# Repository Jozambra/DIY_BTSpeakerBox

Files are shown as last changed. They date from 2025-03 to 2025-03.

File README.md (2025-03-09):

# DIY_BTSpeakerBox
This project presents a DIY design for a speaker box that can recieve audio data from an analog 3.5mm Jack or a BT module. It incorporates a 3-band Equalizer custom PCB that also functions as the main power distribution board.

The main components of the board are present in the HW wiring diagram attached; it consits of a main PCB that incorporates a PreAmp with 3 band EQ, a BT audio reciever module, and a 30W stereo class D amplifier. A 3D encasing is also provided (Step and FreeCAD project files are included in the Enclosure branch). A generic BT and Class D amp modules are used in this project; however, the main PCB is compatible with any alternative solution (either custom or commercial) that uses a similar voltage. Nontheless, note that the main PS (which is, effectively, directly connected to the amp) must be of at least 12V to ensure the proper operation of the 9V regulator.

This amplifier set up has been tested with a 12V 3A power supply over a low-medium volume range; over a 2 hour listening session no excessive heating was detected in either module of the product.

NOTE: A Mains to 12-24V power supply is not included in this design, it recieved power from a standard barrel adaptor using an external supply. It is highly recommeded to use a good quality supply to reduce noise in the PreAmp (This alternative has provided decent results during testing: https://a.co/d/3dhSiTF).

NOTE2: Rev 1.1 is the modified version of the main PCB with some mods from the Rev 1.0 already installed. this design is not tested; however, only minor changes were made so its functionallity is highly likely

Bellow is a list of the current known issues of the project:

-Main PCB is missing mounting wholes for easy attachment to the box (included in the newest revision but missing on the 3D desingn file).
-Noise floor of the PreAmp is noticeable at low volumes (TO DO: reduce all resistances by a factor of 10 and consider using non-carbon based resistors to reduce thermal noise)
-Missing Soft Start circuit to prevent Popping on Speakers during Power-Up/Down.
-Certain combinations of the bass/tremble/mid potentiometers generate an audible oscillation that is transmitted to the spakers; needs further investigation in the filter Op-Amp loop.

Feel free to adapt this project to your particular needs, all the design files are provided as Open Source. Furthermore, if a solution to any of the listed issues is found, a pull request with the approach would be highly appreciated.

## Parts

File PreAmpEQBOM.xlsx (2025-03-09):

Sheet: PreAmpEQR1.0
Reference | Value | Qty | Datasheet | Footprint | DNP | added
C1,C2 | 1n | 2 | ~ | Capacitor_SMD:C_0805_2012Metric_Pad1.18x1.45mm_HandSolder
C3,C8 | 330n | 2 | ~ | Capacitor_SMD:C_0805_2012Metric_Pad1.18x1.45mm_HandSolder
C4,C6 | 200n | 2 | ~ | Capacitor_SMD:C_0805_2012Metric_Pad1.18x1.45mm_HandSolder
C5,C12,C14,C19,C20,C21,C22 | 10u | 7 | ~ | Capacitor_SMD:C_0805_2012Metric_Pad1.18x1.45mm_HandSolder
C7 | 1u | 1 | ~ | Capacitor_SMD:C_0805_2012Metric_Pad1.18x1.45mm_HandSolder
C9,C10,C17,C18,C31 | 100n | 5 | ~ | Capacitor_SMD:C_0805_2012Metric_Pad1.18x1.45mm_HandSolder
C11,C13 | 33p | 2 | ~ | Capacitor_SMD:C_0805_2012Metric_Pad1.18x1.45mm_HandSolder
C15,C16 | 2.2u | 2 | ~ | Capacitor_SMD:C_0805_2012Metric_Pad1.18x1.45mm_HandSolder
C23,C29 | 22n | 2 | ~ | Capacitor_SMD:C_0805_2012Metric_Pad1.18x1.45mm_HandSolder
C24,C28 | 4.7n | 2 | ~ | Capacitor_SMD:C_0805_2012Metric_Pad1.18x1.45mm_HandSolder
C25,C27 | 47n | 2 | ~ | Capacitor_SMD:C_0805_2012Metric_Pad1.18x1.45mm_HandSolder
C26,C30 | 10n | 2 | ~ | Capacitor_SMD:C_0805_2012Metric_Pad1.18x1.45mm_HandSolder
CR1 | VSSAF510-M3/H | 1 | VSSAF510-M3/H | CR_SLIMSMA_DO-221AC_VIS
F1 | MF-GSMF300/36X-2 | 1 | MF-GSMF300/36X-2 | MFGSM:FUSE_MF-GSMF_BRN
J1 | DCJ200-10-A-XX-K_REVA | 1 |  | DCJ200:GCT_DCJ200-10-A-XX-K_REVA
J2,J5 | 1935174 | 2 |  | TERM BLK 3POS:PHOENIX_1935174
J3,J4,J6 | 691137710002 | 3 |  | TERM BLK 2POS:691137710002
L1 | ACM7060-701-2PL-TL01 | 1 | ACM7060-701-2PL-TL01 | ACM7060:IND_ACM7060_TDK
R1 | 0R | 1 | ~ | Resistor_SMD:R_0805_2012Metric_Pad1.20x1.40mm_HandSolder
R2,R5,R7 | DNI | 3 | ~ | Resistor_SMD:R_0805_2012Metric_Pad1.20x1.40mm_HandSolder
R3,R4,R13,R14,R15,R24,R25,R26 | 10k | 8 | ~ | Resistor_SMD:R_0805_2012Metric_Pad1.20x1.40mm_HandSolder
R6,R8,R32,R35 | 50k | 4 | ~ | Resistor_SMD:R_0805_2012Metric_Pad1.20x1.40mm_HandSolder
R9,R10,R11,R12 | PTN16-A100230K1B2 | 4 |  | PTN16:POT_PTN16-A100230K1B2
R16,R17,R18,R19 | 44k | 4 | ~ | Resistor_SMD:R_0805_2012Metric_Pad1.20x1.40mm_HandSolder
R20,R21,R27,R28 | 3.3k | 4 | ~ | Resistor_SMD:R_0805_2012Metric_Pad1.20x1.40mm_HandSolder
R22,R23,R29,R30 | 3.6k | 4 | ~ | Resistor_SMD:R_0805_2012Metric_Pad1.20x1.40mm_HandSolder
R31,R33 | 25k | 2 | ~ | Resistor_SMD:R_0805_2012Metric_Pad1.20x1.40mm_HandSolder
R34,R36 | 20k | 2 | ~ | Resistor_SMD:R_0805_2012Metric_Pad1.20x1.40mm_HandSolder
RV1 | AVRH16A2C270KT200NA8 | 1 | ~ | Resistor_SMD:R_0603_1608Metric_Pad0.98x0.95mm_HandSolder
U1 | NCV7805BDTRKG | 1 | NCV7805BDTRKG | DPAK-3_ONS
U2 | NCV7809BD2TR4G | 1 | NCV7809BD2TR4G | D2PAK3_ONS
U3,U4,U5 | LM833MX/NOPB | 3 | LM833MX/NOPB | LM833MX:M08A_TEX

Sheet: PreAmpEQ_R1.1
Reference | Value | Datasheet | Footprint | Qty | DNP
C1,C2 | 1n | ~ | Capacitor_SMD:C_0805_2012Metric_Pad1.18x1.45mm_HandSolder | 2
C3,C8 | 330n | ~ | Capacitor_SMD:C_0805_2012Metric_Pad1.18x1.45mm_HandSolder | 2
C4,C6 | 200n | ~ | Capacitor_SMD:C_0805_2012Metric_Pad1.18x1.45mm_HandSolder | 2
C5,C12,C14,C19,C20,C21,C22 | 10u | ~ | Capacitor_SMD:C_0805_2012Metric_Pad1.18x1.45mm_HandSolder | 7
C7 | 1u | ~ | Capacitor_SMD:C_0805_2012Metric_Pad1.18x1.45mm_HandSolder | 1
C9,C10,C17,C18,C31 | 100n | ~ | Capacitor_SMD:C_0805_2012Metric_Pad1.18x1.45mm_HandSolder | 5
C11,C13 | 33p | ~ | Capacitor_SMD:C_0805_2012Metric_Pad1.18x1.45mm_HandSolder | 2
C15,C16 | 2.2u | ~ | Capacitor_SMD:C_0805_2012Metric_Pad1.18x1.45mm_HandSolder | 2
C23,C29 | 22n | ~ | Capacitor_SMD:C_0805_2012Metric_Pad1.18x1.45mm_HandSolder | 2
C24,C28 | 4.7n | ~ | Capacitor_SMD:C_0805_2012Metric_Pad1.18x1.45mm_HandSolder | 2
C25,C27 | 47n | ~ | Capacitor_SMD:C_0805_2012Metric_Pad1.18x1.45mm_HandSolder | 2
C26,C30 | 10n | ~ | Capacitor_SMD:C_0805_2012Metric_Pad1.18x1.45mm_HandSolder | 2
C32,C33 | 22u | ~ | Capacitor_SMD:C_0805_2012Metric_Pad1.18x1.45mm_HandSolder | 2
CR1 | VSSAF510-M3/H | VSSAF510-M3/H | CR_SLIMSMA_DO-221AC_VIS | 1
F1 | MF-GSMF300/36X-2 | MF-GSMF300/36X-2 | MFGSM:FUSE_MF-GSMF_BRN | 1
J1 | DCJ200-10-A-XX-K_REVA |  | DCJ200:GCT_DCJ200-10-A-XX-K_REVA | 1
J2,J5 | 1935174 |  | TERM BLK 3POS:PHOENIX_1935174 | 2
J3,J4,J6 | 691137710002 |  | TERM BLK 2POS:691137710002 | 3
L1 | ACM7060-701-2PL-TL01 | ACM7060-701-2PL-TL01 | ACM7060:IND_ACM7060_TDK | 1
R1 | 0R | ~ | Resistor_SMD:R_0805_2012Metric_Pad1.20x1.40mm_HandSolder | 1
R2 | DNI | ~ | Resistor_SMD:R_0805_2012Metric_Pad1.20x1.40mm_HandSolder | 1
R3,R4,R13,R14,R15,R24,R25,R26 | 10k | ~ | Resistor_SMD:R_0805_2012Metric_Pad1.20x1.40mm_HandSolder | 8
R5,R7 | 11k3 | ~ | Resistor_SMD:R_0805_2012Metric_Pad1.20x1.40mm_HandSolder | 2
R6,R8,R32,R35 | 50k | ~ | Resistor_SMD:R_0805_2012Metric_Pad1.20x1.40mm_HandSolder | 4
R9,R10,R11,R12 | PTN16-A100230K1B2 |  | PTN16:POT_PTN16-A100230K1B2 | 4
R16,R17,R18,R19,R37,R38,R39,R40 | 22k | ~ | Resistor_SMD:R_0805_2012Metric_Pad1.20x1.40mm_HandSolder | 8
R20,R21,R27,R28 | 3.3k | ~ | Resistor_SMD:R_0805_2012Metric_Pad1.20x1.40mm_HandSolder | 4
R22,R23,R29,R30 | 3.6k | ~ | Resistor_SMD:R_0805_2012Metric_Pad1.20x1.40mm_HandSolder | 4
R31,R33 | 25k | ~ | Resistor_SMD:R_0805_2012Metric_Pad1.20x1.40mm_HandSolder | 2
R34,R36 | 20k | ~ | Resistor_SMD:R_0805_2012Metric_Pad1.20x1.40mm_HandSolder | 2
R41,R42 | 1k | ~ | Resistor_SMD:R_0805_2012Metric_Pad1.20x1.40mm_HandSolder | 2
RV1 | AVRH16A2C270KT200NA8 | ~ | Resistor_SMD:R_0603_1608Metric_Pad0.98x0.95mm_HandSolder | 1
U1 | NCV7805BDTRKG | NCV7805BDTRKG | DPAK-3_ONS | 1
U2 | NCV7809BD2TR4G | NCV7809BD2TR4G | D2PAK3_ONS | 1
U3,U4,U5 | LM833MX/NOPB | LM833MX/NOPB | LM833MX:M08A_TEX | 3
BT module | VHM-314 | VHM-314 | https://www.aliexpress.com/item/1005006614243125.html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 | 1
3.5 mm Plug | ACJS-MV35-3 | ACJS-MV35-3 |  | 1
DPDT switch | SW-T3-4B-A-A3-S2 | SW-T3-4B-A-A3-S2 |  | 1
SpeakerOutConnertor | Push-In Jack |  | https://www.aliexpress.com/item/1005008159607589.html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 | 1
Power amp | TPA3110 | TPA3110 | https://www.aliexpress.com/item/1005006124814134.html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 | 1
Notes: | All caps in the power lines must be rated at least at 50V
 | All caps should use X7R or X5R materials
 | All sinal caps should be at least 25 V
 | The lower resistor tolerance the better
 | All chip components are 0805s

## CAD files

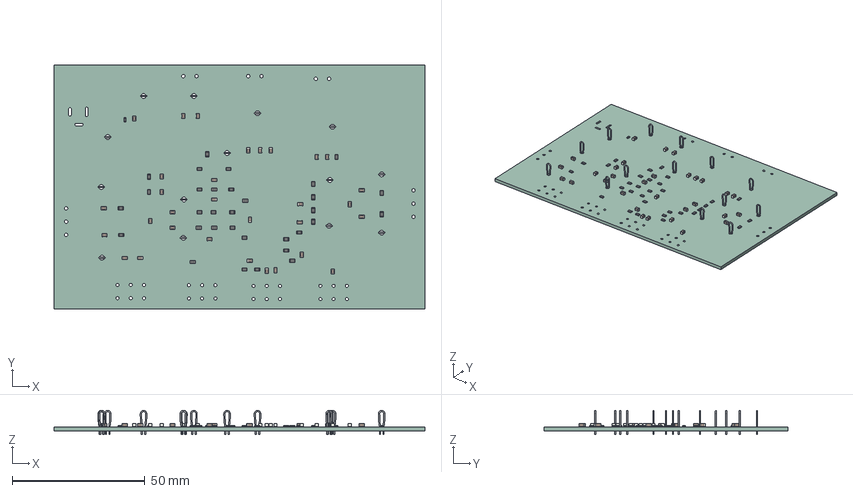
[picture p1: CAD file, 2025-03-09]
PreAmpEQ/PreAmpEQ.step
140.0 x 92.2 x 9.15 mm
R_0805_2012Metric x 32
TestPoint_Loop_D2.50mm_Drill1.85mm x 14
C_0805_2012Metric x 31
R_0603_1608Metric
PreAmpEQ_PCB

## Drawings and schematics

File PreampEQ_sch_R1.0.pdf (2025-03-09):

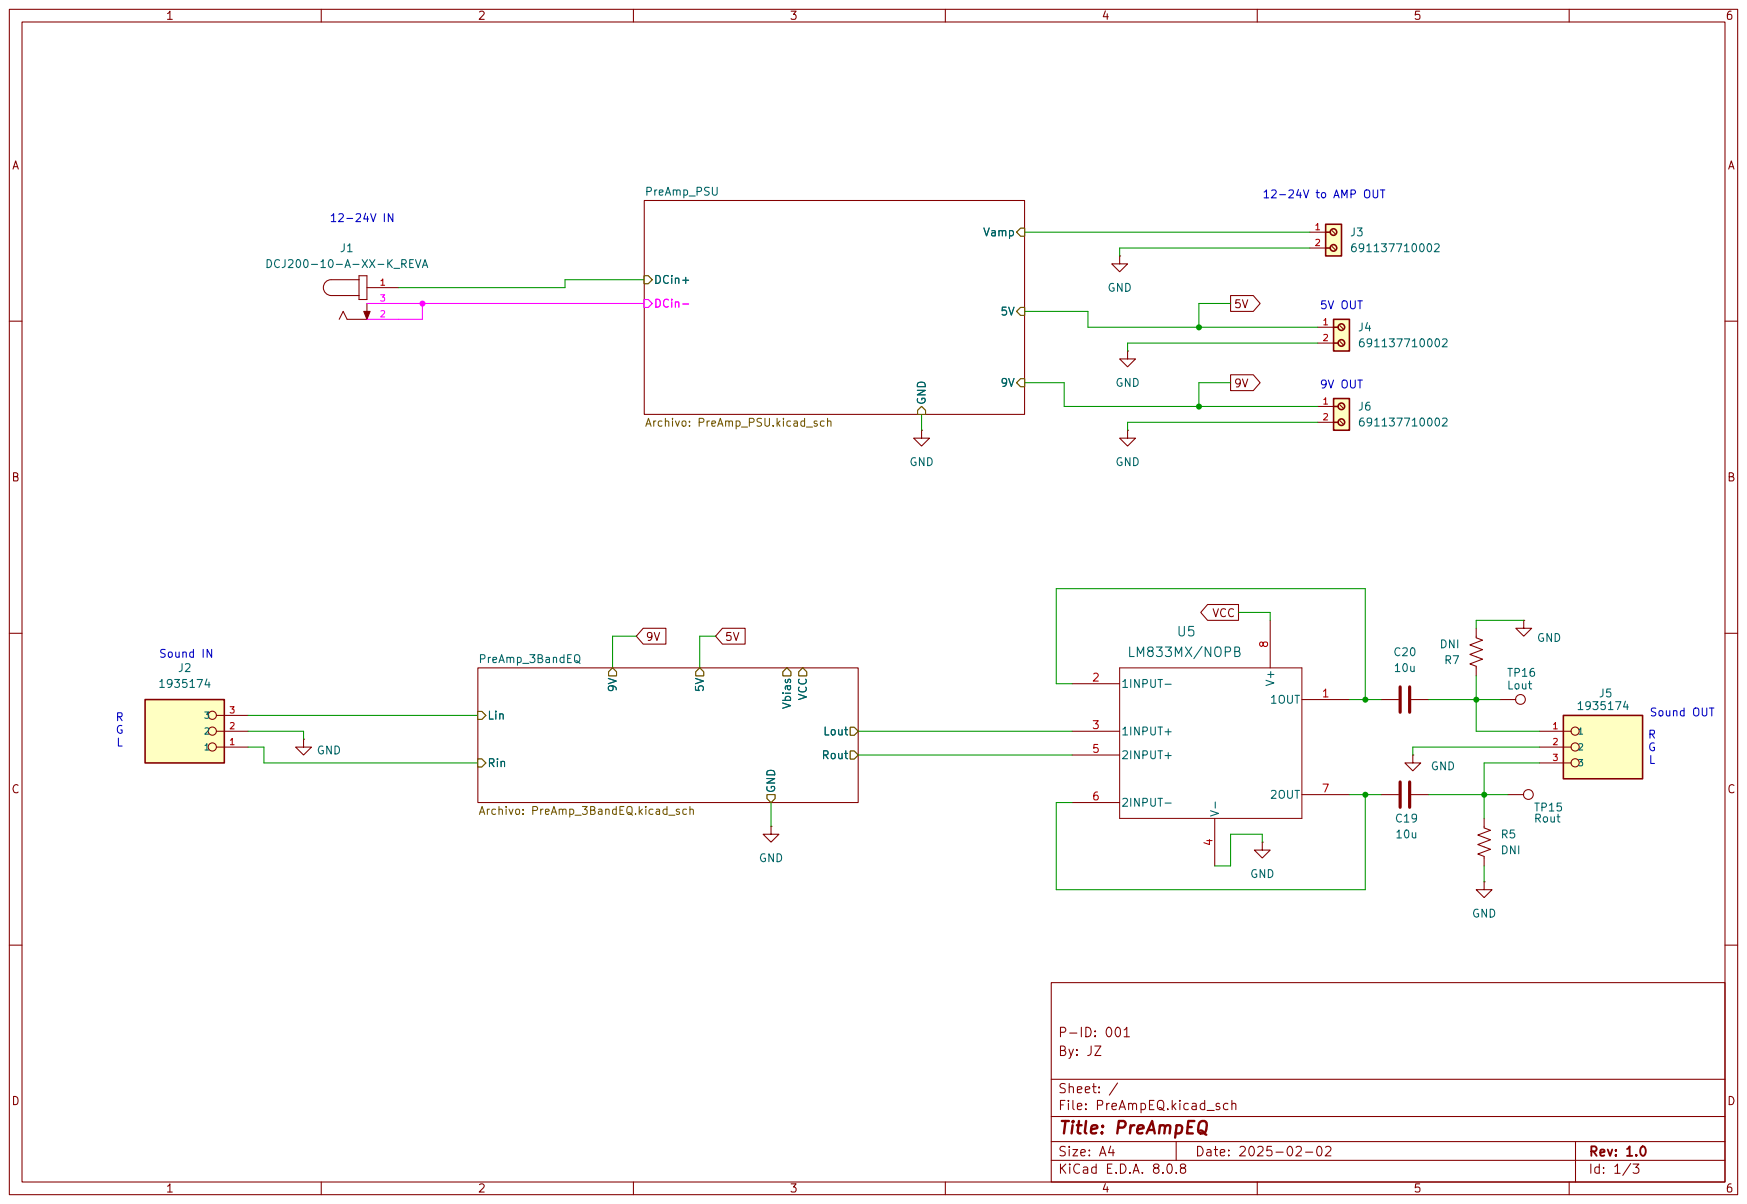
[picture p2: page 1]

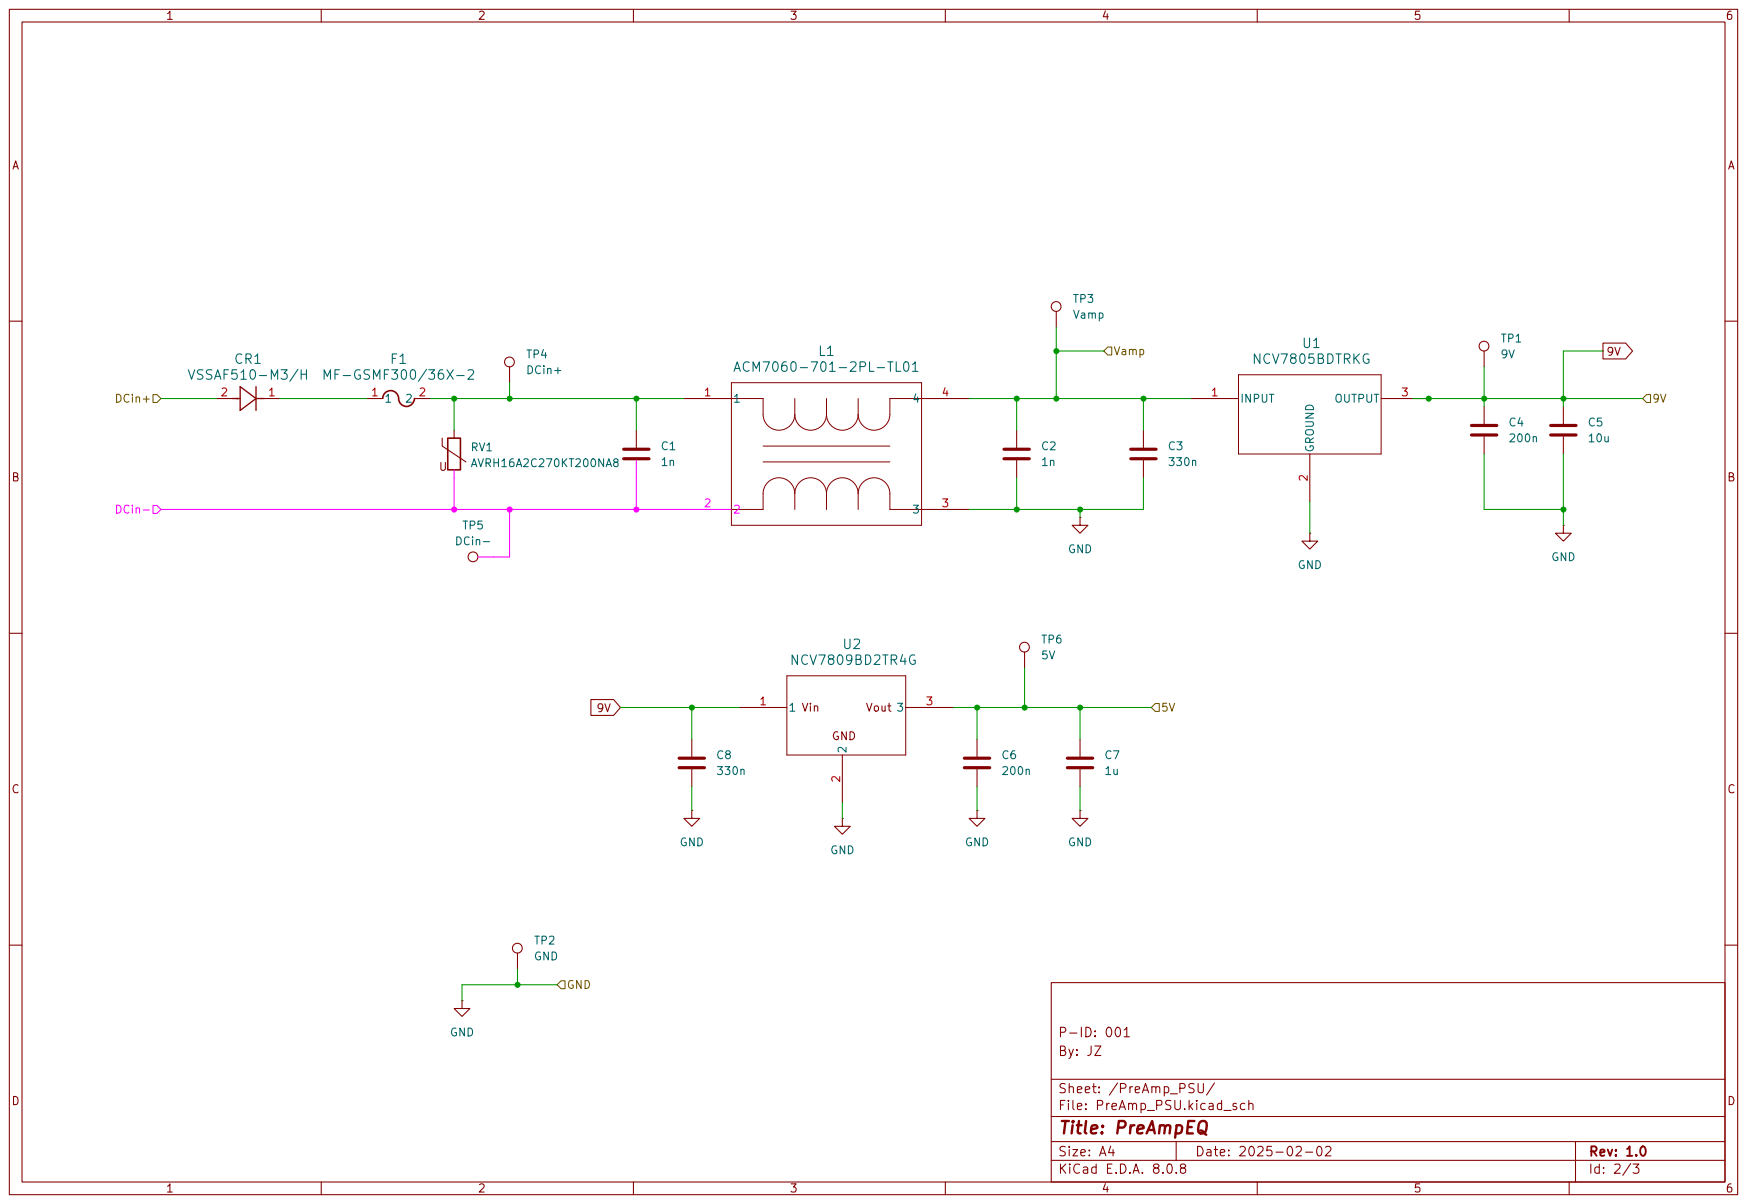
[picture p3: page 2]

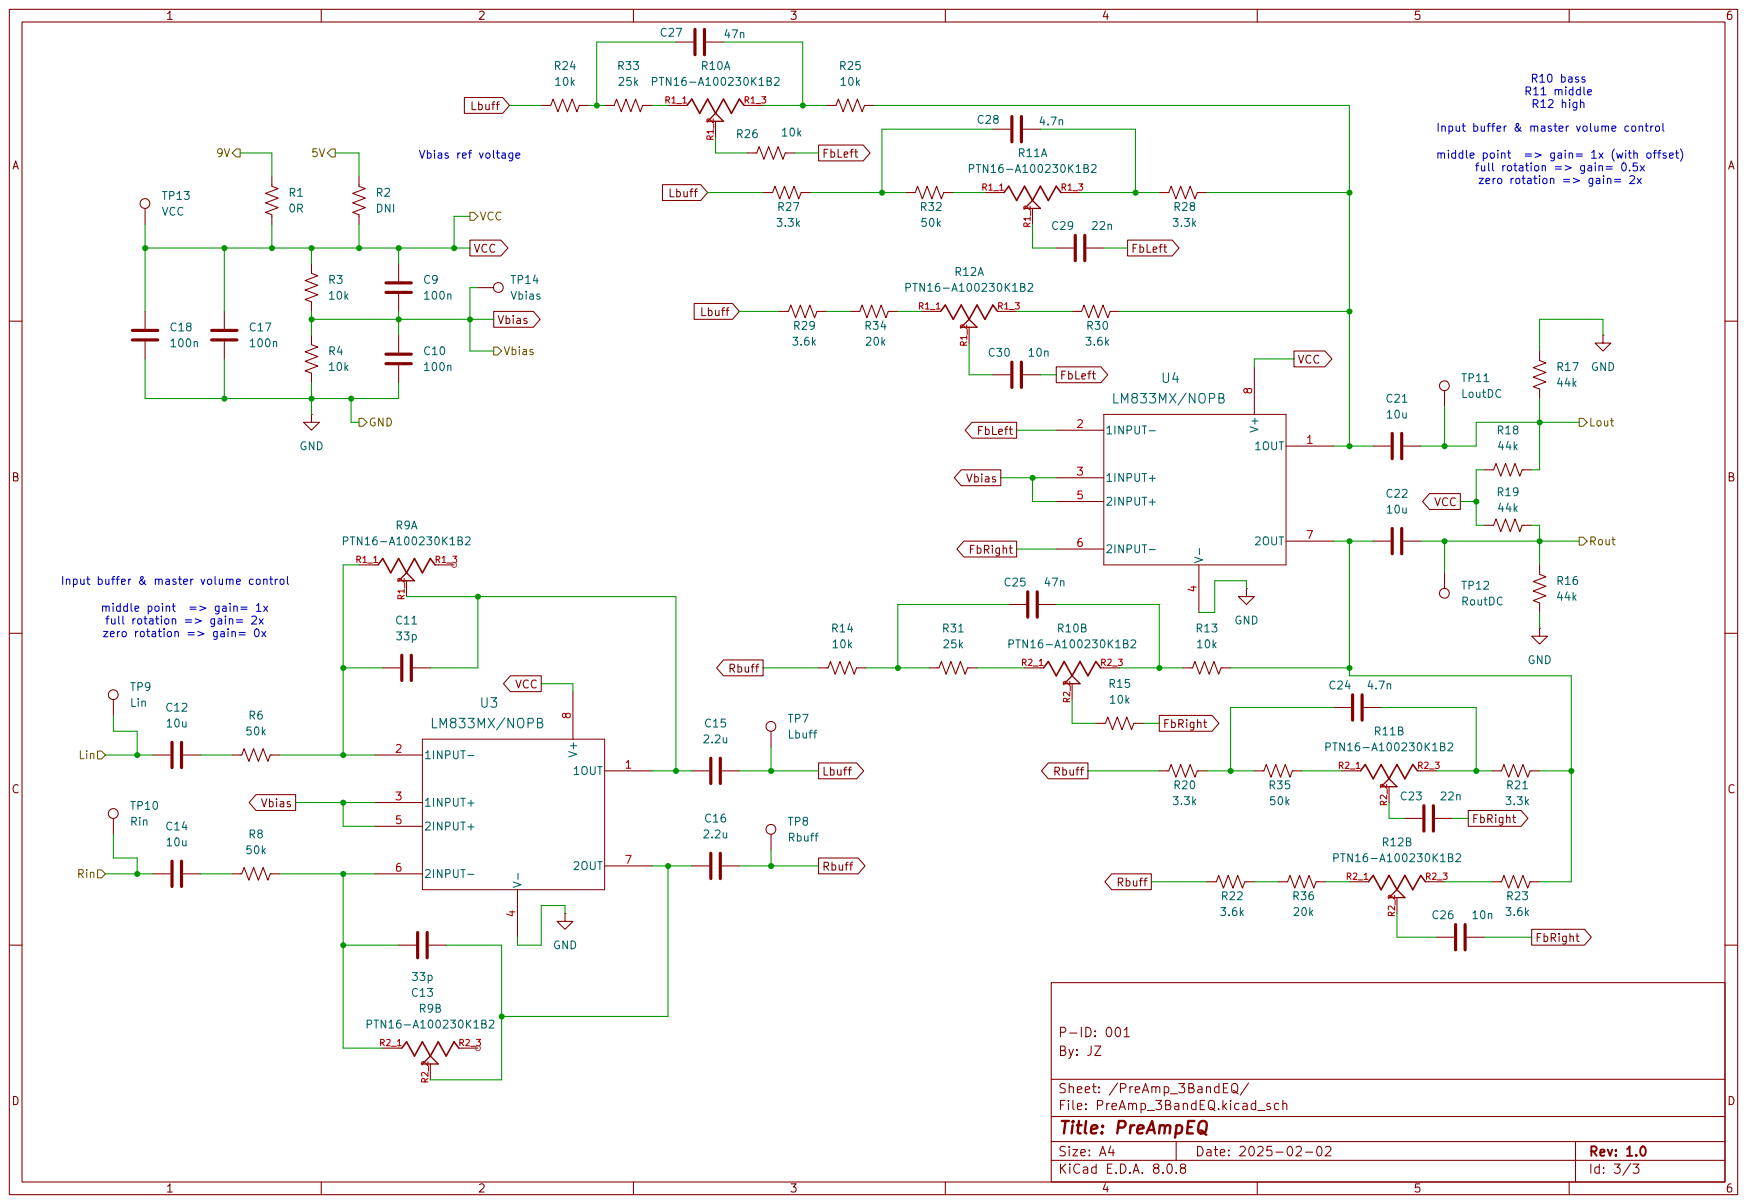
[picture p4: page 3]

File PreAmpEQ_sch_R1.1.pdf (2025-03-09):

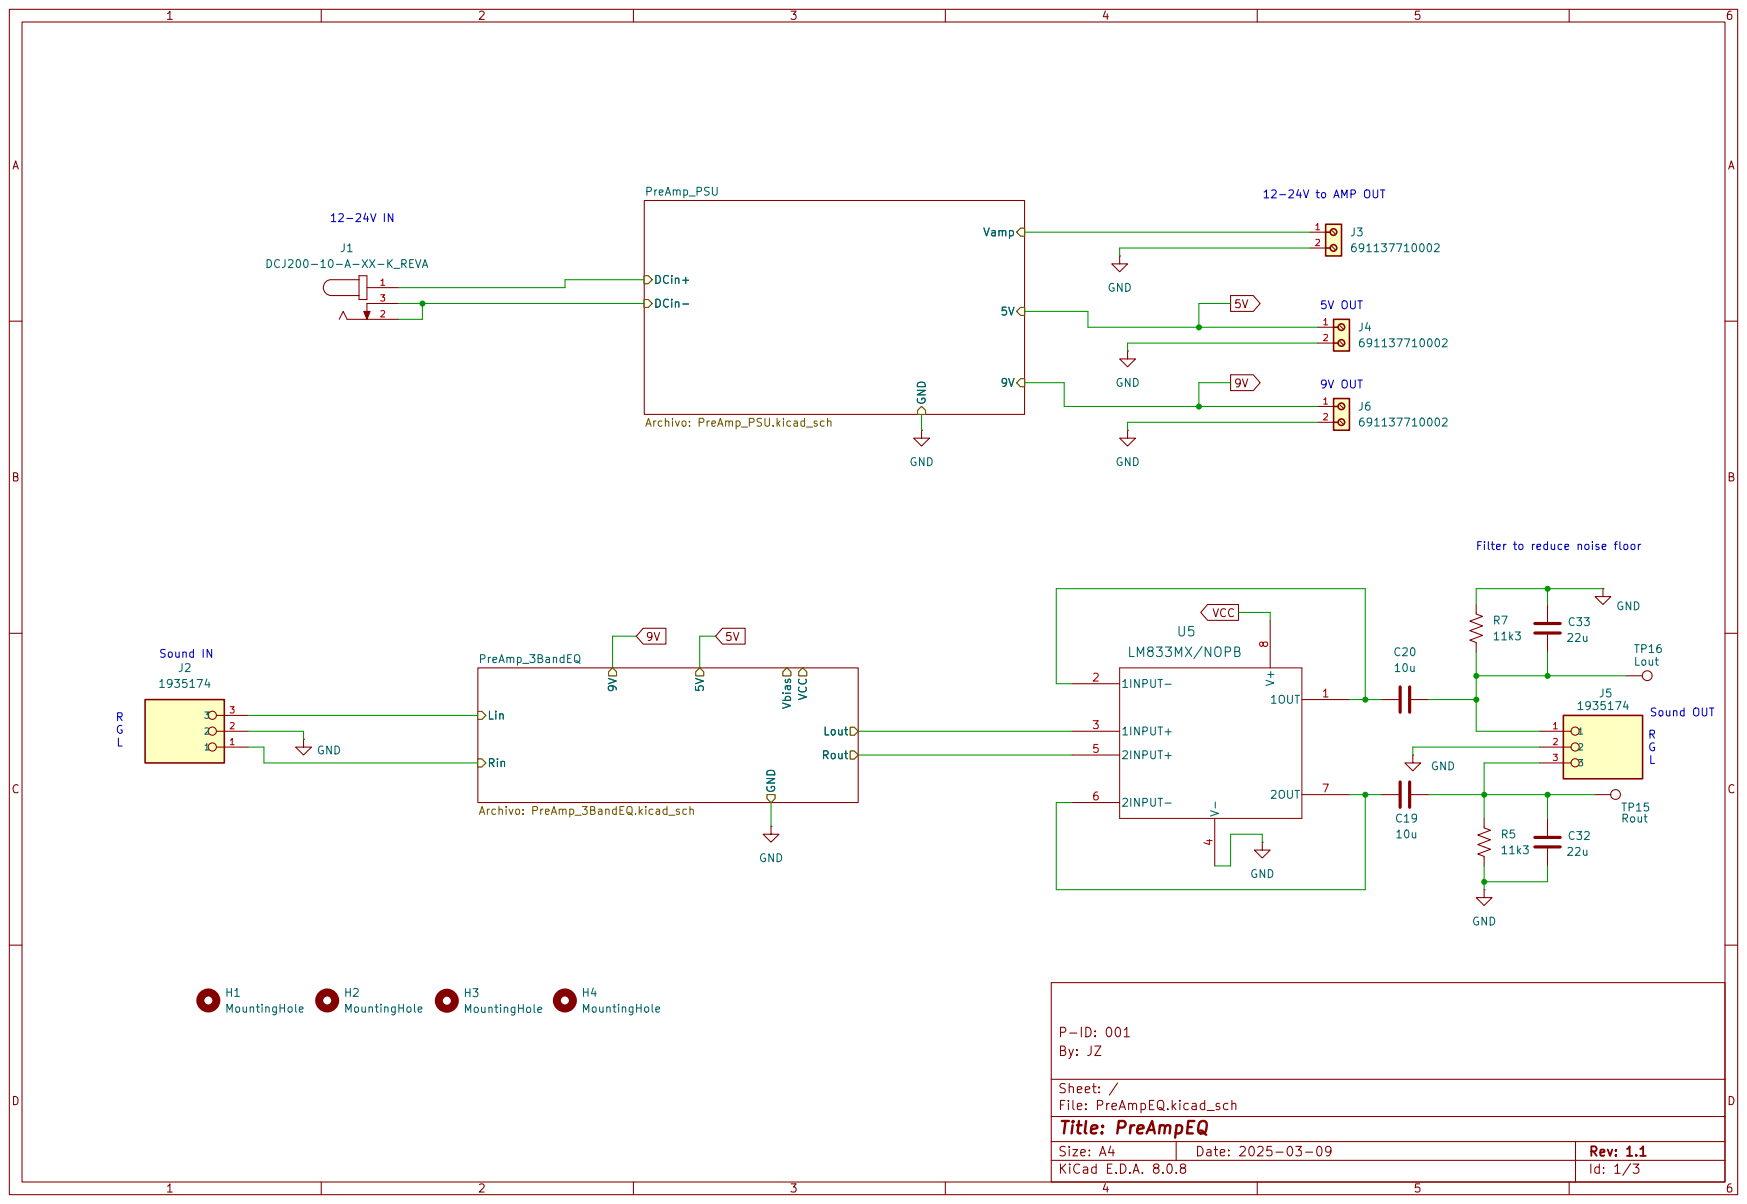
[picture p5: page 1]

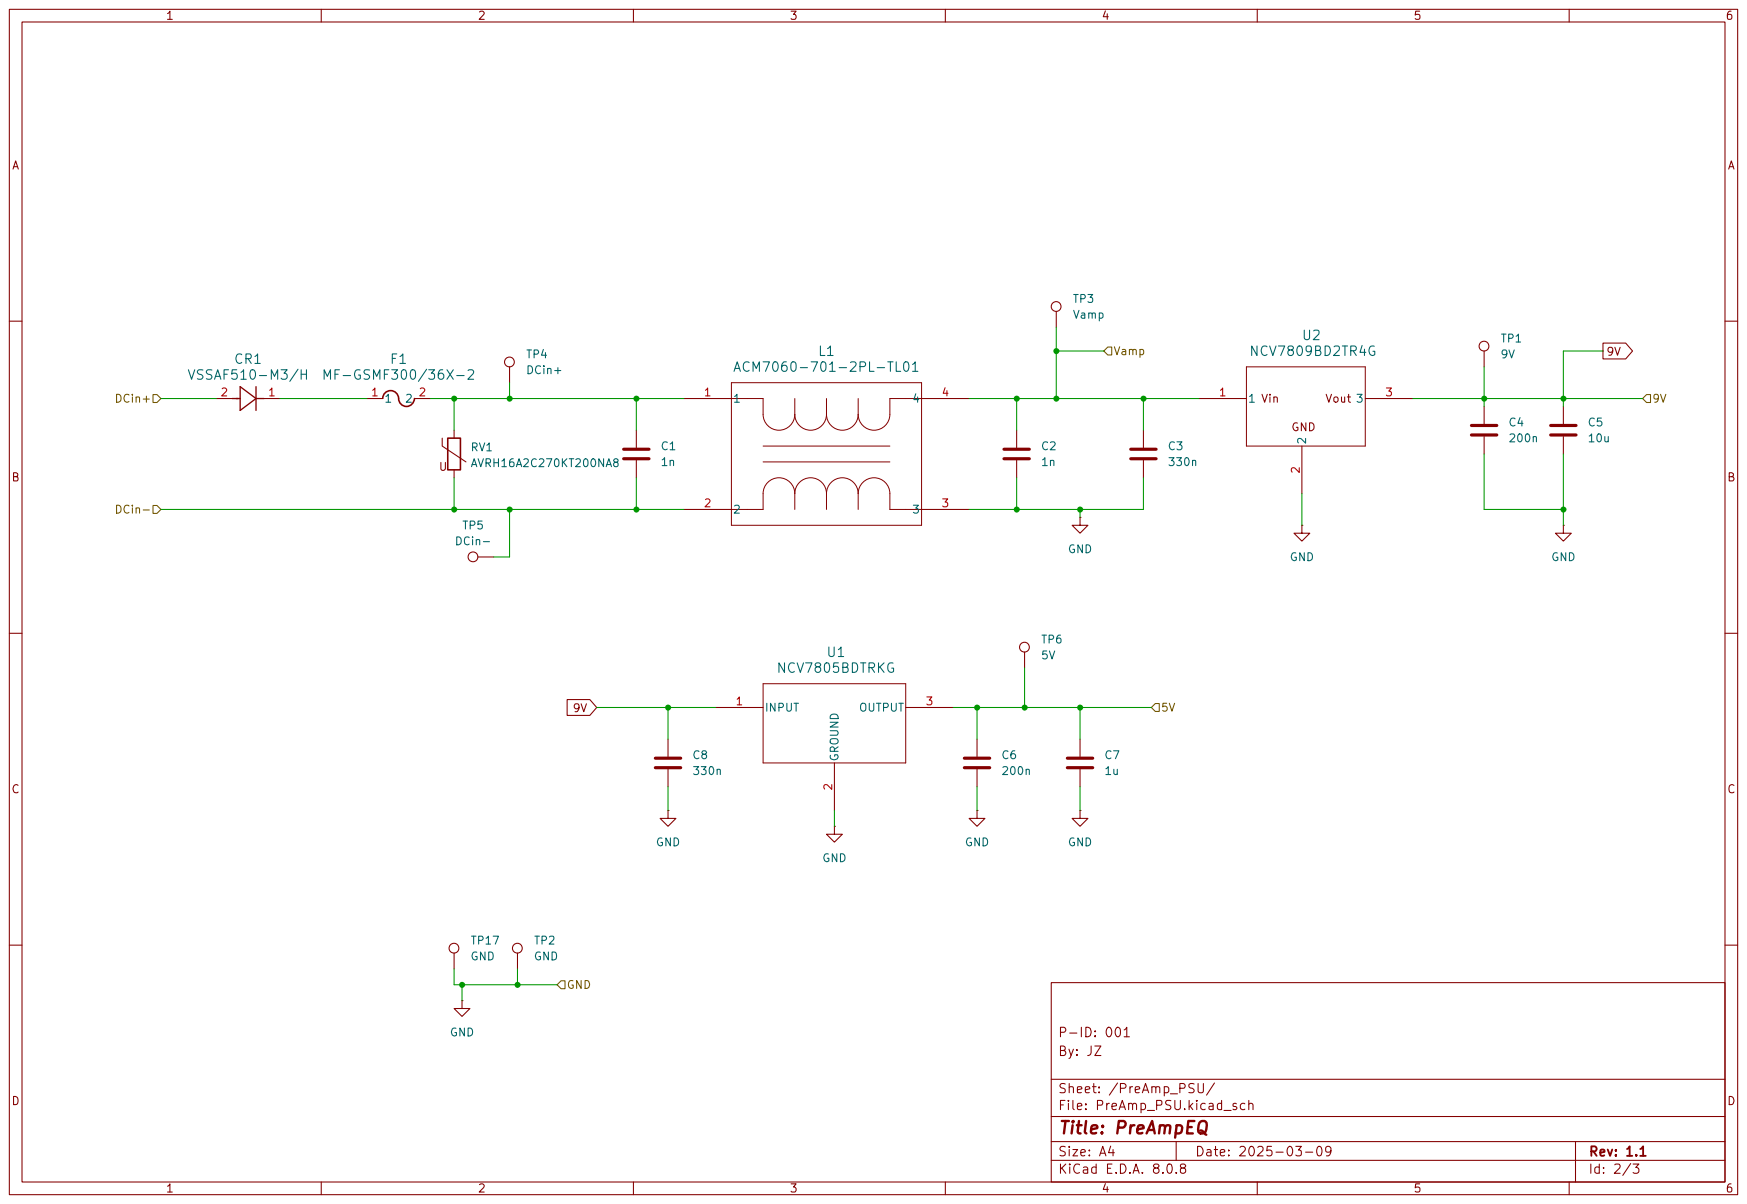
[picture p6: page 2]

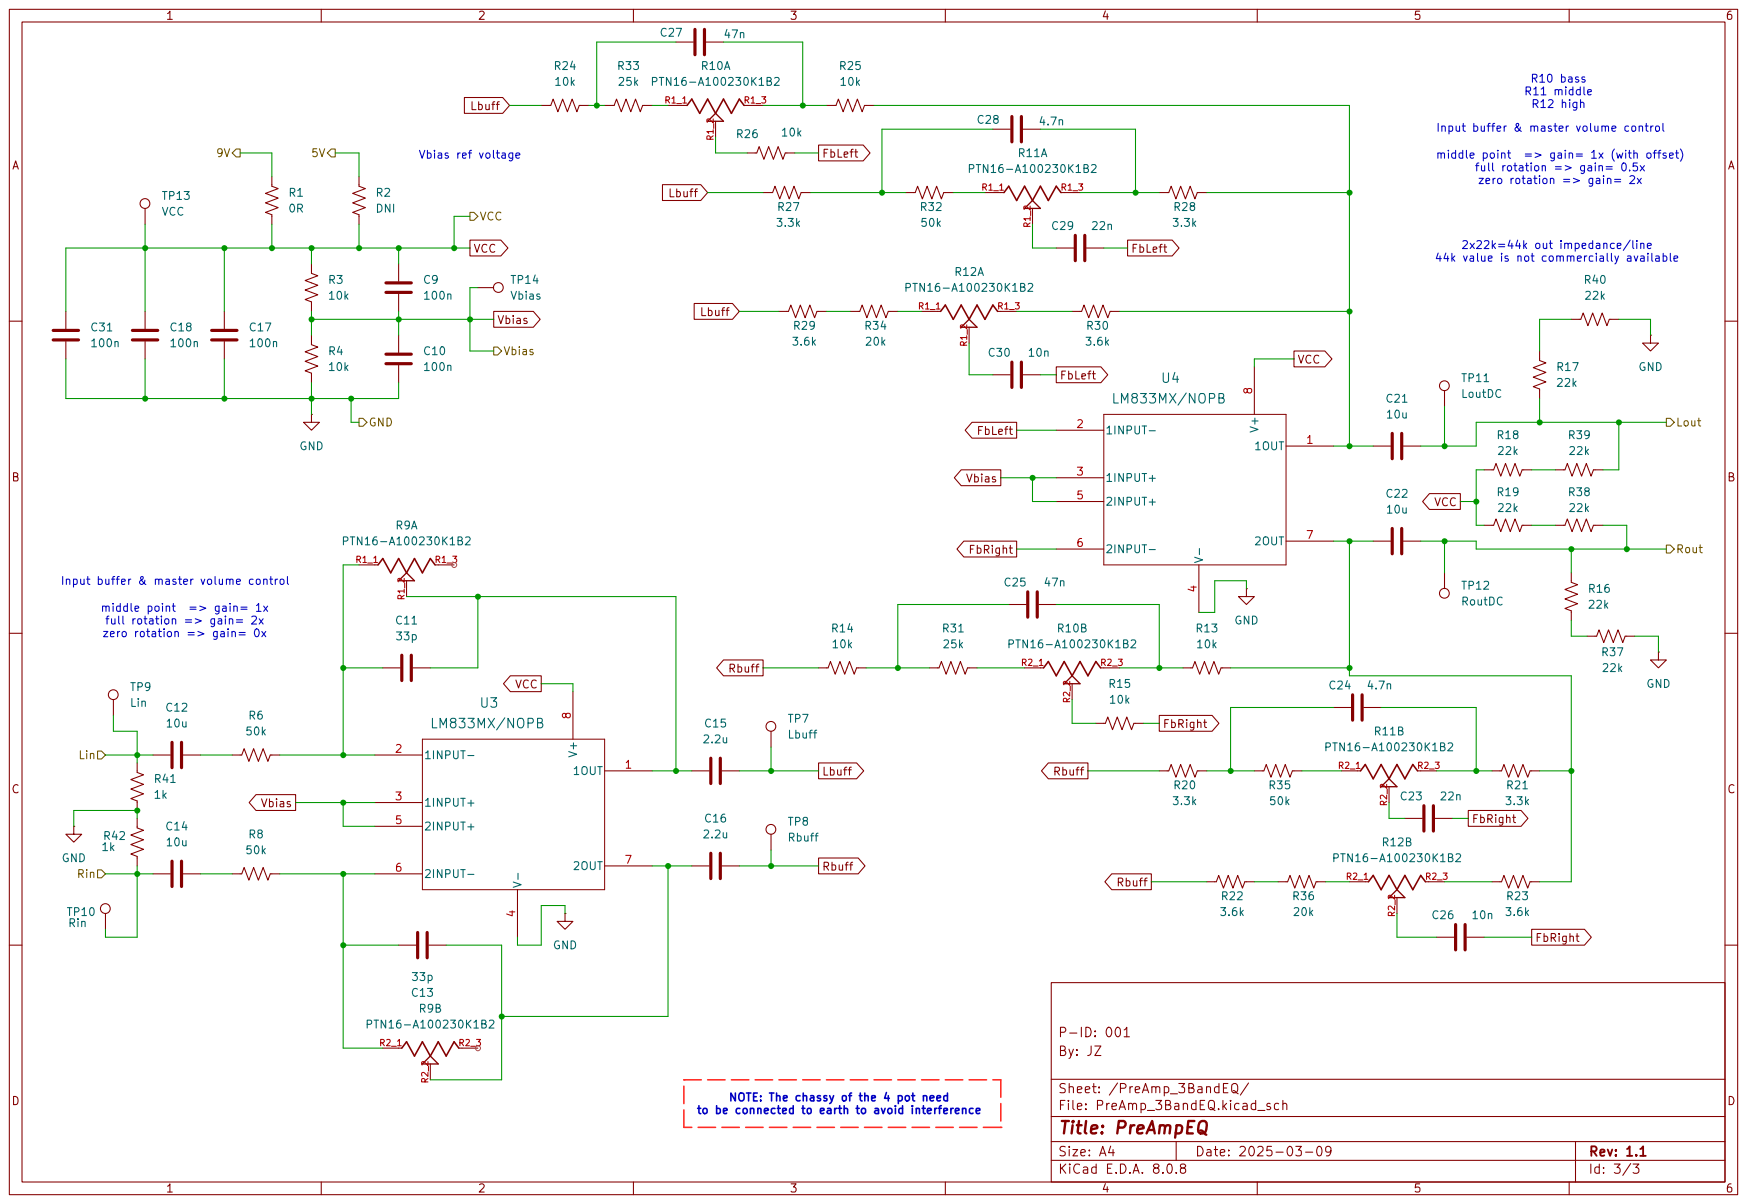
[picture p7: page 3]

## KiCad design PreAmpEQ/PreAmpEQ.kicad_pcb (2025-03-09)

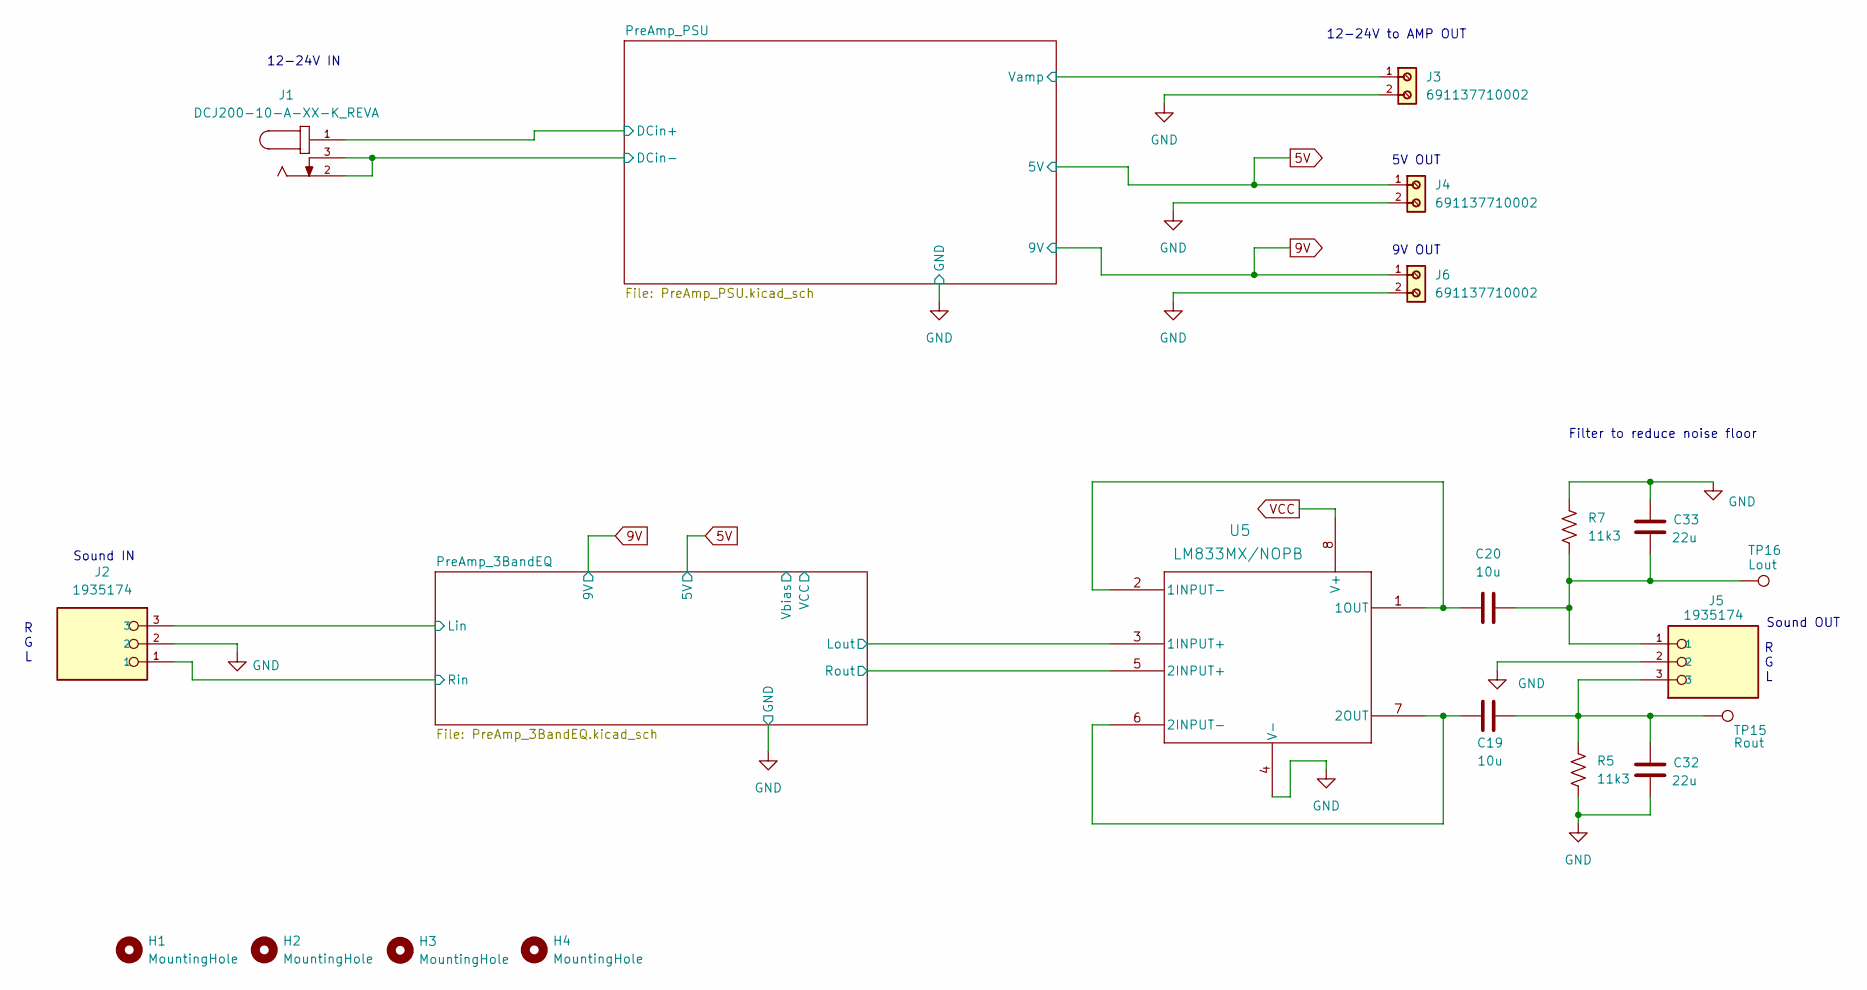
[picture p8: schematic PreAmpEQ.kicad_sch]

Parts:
C19, C20: 10u; C_0805_2012Metric_Pad1.18x1.45mm_HandSolder
C32, C33: 22u; C_0805_2012Metric_Pad1.18x1.45mm_HandSolder
H1, H2, H3, H4: MountingHole; MountingHole_3.2mm_M3
J1: DCJ200-10-A-XX-K_REVA; GCT_DCJ200-10-A-XX-K_REVA; PARTREV A
J2, J5: 1935174; PHOENIX_1935174
J3, J4, J6: 691137710002; PART-NUMBER 691137710002
R5, R7: 11k3; R_0805_2012Metric_Pad1.20x1.40mm_HandSolder
TP15: Rout; TestPoint_Loop_D2.50mm_Drill1.85mm
TP16: Lout; TestPoint_Loop_D2.50mm_Drill1.85mm
U5: LM833MX/NOPB; M08A_TEX

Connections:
5V: J4.1; also elsewhere on the board
9V: J6.1; also elsewhere on the board
/PreAmp_3BandEQ/Lin: J2.3; also elsewhere on the board
/PreAmp_3BandEQ/Lout: U5.3 (1INPUT+); also elsewhere on the board
/PreAmp_3BandEQ/Rin: J2.1; also elsewhere on the board
/PreAmp_3BandEQ/Rout: U5.5 (2INPUT+); also elsewhere on the board
/PreAmp_PSU/DCin+: J1.1; also elsewhere on the board
/PreAmp_PSU/DCin-: J1.2, J1.3; also elsewhere on the board
/PreAmp_PSU/Vamp: J3.1; also elsewhere on the board
GND: C32.2, C33.1, J2.2, J3.2, J4.2, J5.2, J6.2, R5.2, R7.2, U5.4 (V-); also elsewhere on the board
unnamed: C19.1, C32.1, J5.3, R5.1, TP15.1
unnamed: C20.2, C33.2, J5.1, R7.1, TP16.1
unnamed: C20.1, U5.1 (1OUT), U5.2 (1INPUT-)
unnamed: C19.2, U5.6 (2INPUT-), U5.7 (2OUT)
VCC: U5.8 (V+); also elsewhere on the board

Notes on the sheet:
5V OUT
9V OUT
12-24V IN
Sound OUT
Filter to reduce noise floor
Sound IN
12-24V to AMP OUT
R G L

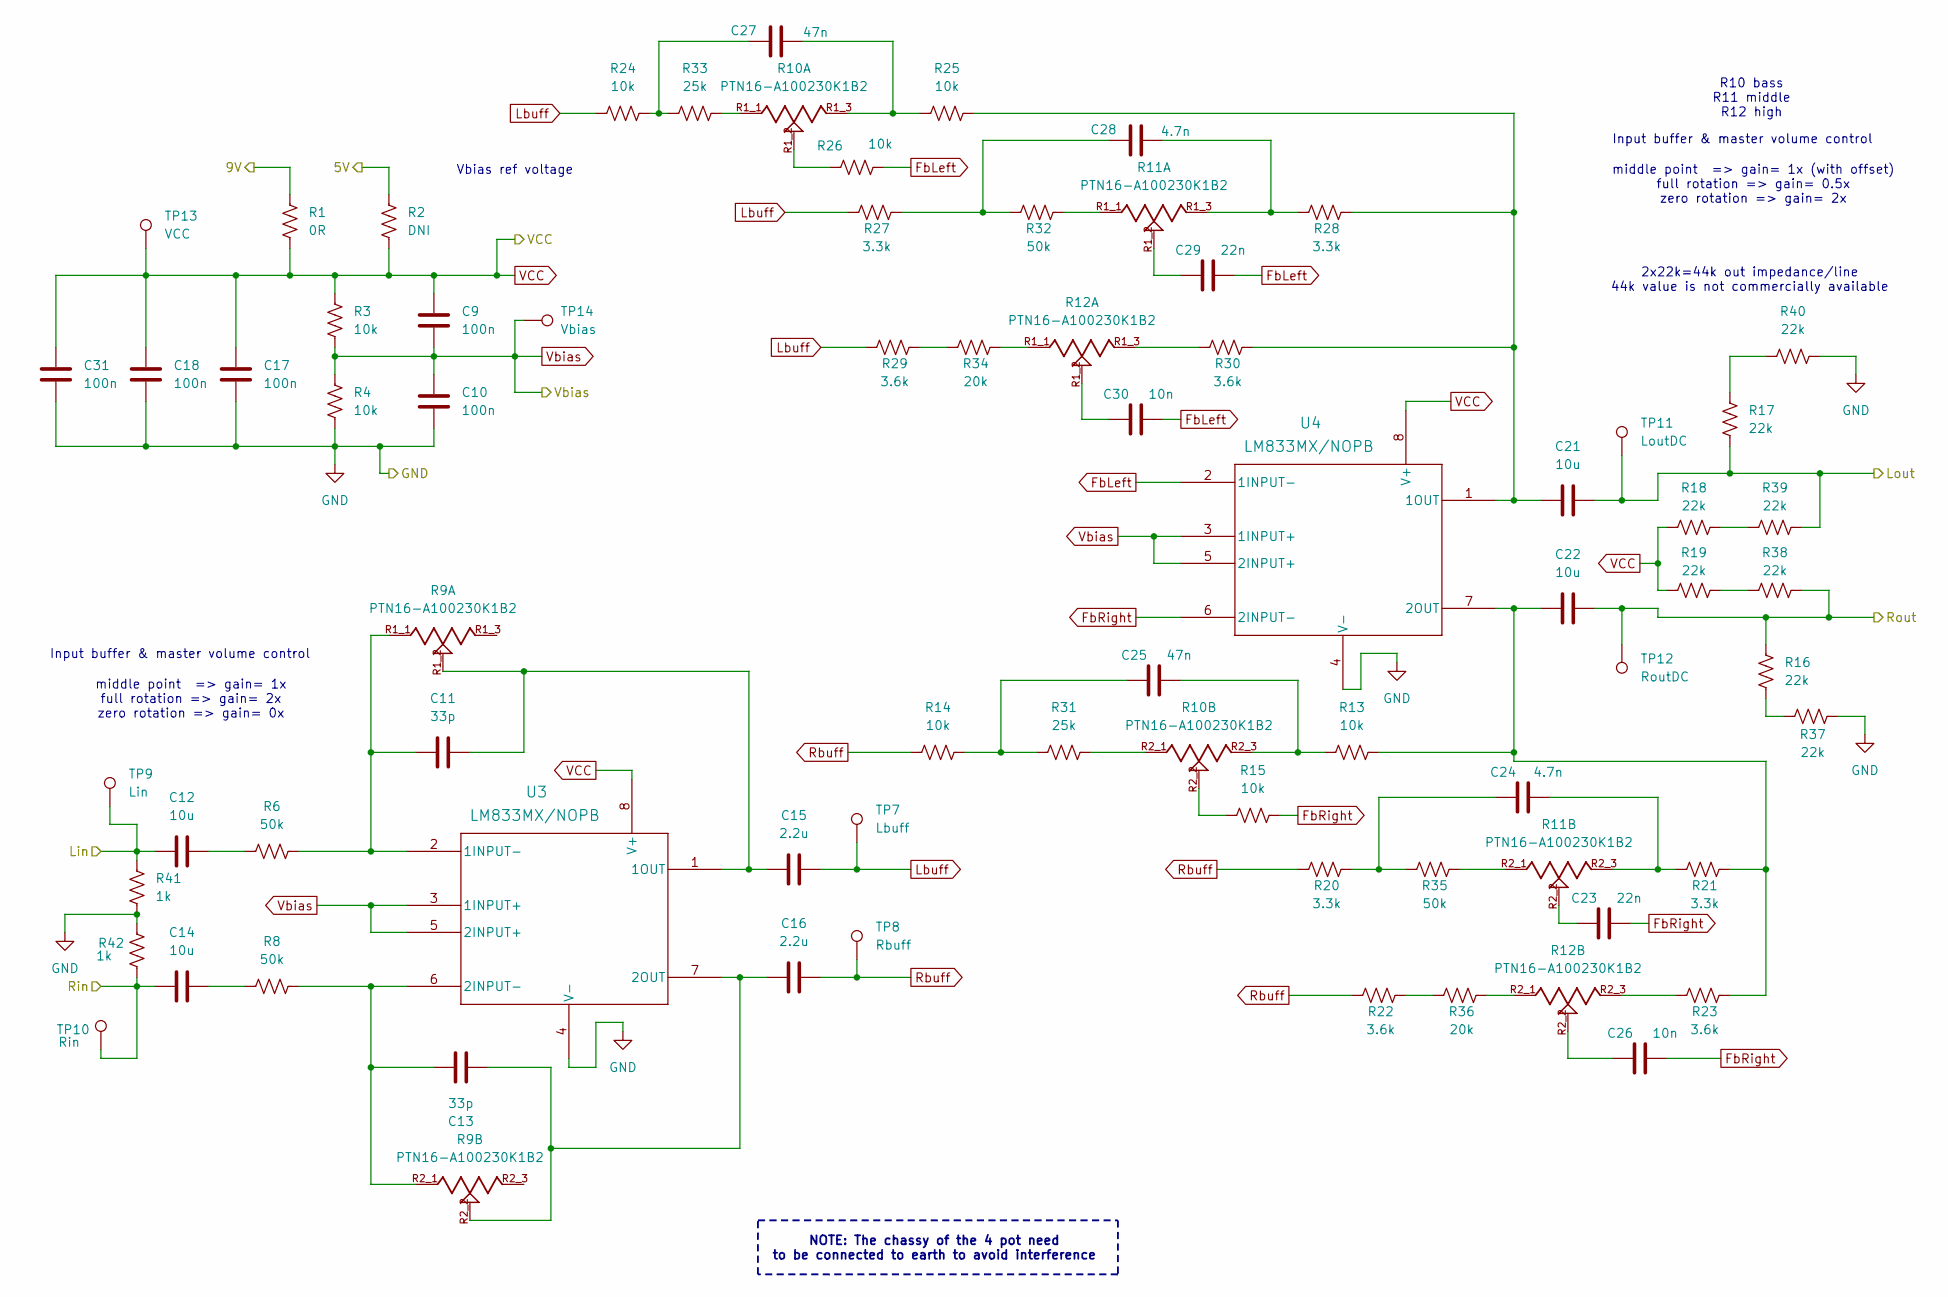
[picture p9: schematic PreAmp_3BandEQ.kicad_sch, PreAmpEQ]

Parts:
C9, C10, C17, C18, C31: 100n; C_0805_2012Metric_Pad1.18x1.45mm_HandSolder
C11, C13: 33p; C_0805_2012Metric_Pad1.18x1.45mm_HandSolder
C12, C14, C21, C22: 10u; C_0805_2012Metric_Pad1.18x1.45mm_HandSolder
C15, C16: 2.2u; C_0805_2012Metric_Pad1.18x1.45mm_HandSolder
C23, C29: 22n; C_0805_2012Metric_Pad1.18x1.45mm_HandSolder
C24, C28: 4.7n; C_0805_2012Metric_Pad1.18x1.45mm_HandSolder
C25, C27: 47n; C_0805_2012Metric_Pad1.18x1.45mm_HandSolder
C26, C30: 10n; C_0805_2012Metric_Pad1.18x1.45mm_HandSolder
R1: 0R; R_0805_2012Metric_Pad1.20x1.40mm_HandSolder
R2: DNI; R_0805_2012Metric_Pad1.20x1.40mm_HandSolder
R3, R4, R13, R14, R15, R24, R25, R26: 10k; R_0805_2012Metric_Pad1.20x1.40mm_HandSolder
R6, R8, R32, R35: 50k; R_0805_2012Metric_Pad1.20x1.40mm_HandSolder
R9, R10, R11, R12: PTN16-A100230K1B2; POT_PTN16-A100230K1B2; PARTREV 1.0
R16, R17, R18, R19, R37, R38, R39, R40: 22k; R_0805_2012Metric_Pad1.20x1.40mm_HandSolder
R20, R21, R27, R28: 3.3k; R_0805_2012Metric_Pad1.20x1.40mm_HandSolder
R22, R23, R29, R30: 3.6k; R_0805_2012Metric_Pad1.20x1.40mm_HandSolder
R31, R33: 25k; R_0805_2012Metric_Pad1.20x1.40mm_HandSolder
R34, R36: 20k; R_0805_2012Metric_Pad1.20x1.40mm_HandSolder
R41, R42: 1k; R_0805_2012Metric_Pad1.20x1.40mm_HandSolder
TP7: Lbuff; TestPoint_Loop_D2.50mm_Drill1.85mm
TP8: Rbuff; TestPoint_Loop_D2.50mm_Drill1.85mm
TP9: Lin; TestPoint_Loop_D2.50mm_Drill1.85mm
TP10: Rin; TestPoint_Loop_D2.50mm_Drill1.85mm
TP11: LoutDC; TestPoint_Loop_D2.50mm_Drill1.85mm
TP12: RoutDC; TestPoint_Loop_D2.50mm_Drill1.85mm
TP13: VCC
TP14: Vbias
U3, U4: LM833MX/NOPB; M08A_TEX

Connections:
5V: R2.1; also elsewhere on the board
9V: R1.1; also elsewhere on the board
/PreAmp_3BandEQ/Lin: C12.1, R41.2, TP9.1; also elsewhere on the board
/PreAmp_3BandEQ/Lout: C21.2, R17.2, R39.2, TP11.1; also elsewhere on the board
/PreAmp_3BandEQ/Rin: C14.1, R42.1, TP10.1; also elsewhere on the board
/PreAmp_3BandEQ/Rout: C22.2, R16.2, R38.2, TP12.1; also elsewhere on the board
FbLeft: C29.2, C30.2, R26.2, U4.2 (1INPUT-)
FbRight: C23.2, C26.2, R15.2, U4.6 (2INPUT-)
GND: C10.2, C17.2, C18.2, C31.2, R4.2, R37.2, R40.2, R41.1, R42.2, U3.4 (V-), U4.4 (V-); also elsewhere on the board
Lbuff: C15.2, R24.1, R27.1, R29.1, TP7.1
unnamed: C12.2, R6.1
unnamed: C14.2, R8.1
unnamed: C23.1, R11.R2_2
unnamed: C24.1, R20.2, R35.1
unnamed: C24.2, R11.R2_3, R21.1
unnamed: C25.1, R14.2, R31.1
unnamed: C25.2, R10.R2_3, R13.1
unnamed: C26.1, R12.R2_2
unnamed: C27.1, R24.2, R33.1
unnamed: C27.2, R10.R1_3, R25.1
unnamed: C28.1, R27.2, R32.1
unnamed: C28.2, R11.R1_3, R28.1
unnamed: C29.1, R11.R1_2
unnamed: C30.1, R12.R1_2
unnamed: R10.R1_1, R33.2
unnamed: R10.R1_2, R26.1
unnamed: R10.R2_1, R31.2
unnamed: R10.R2_2, R15.1
unnamed: R11.R1_1, R32.2
unnamed: R11.R2_1, R35.2
unnamed: R12.R1_1, R34.2
unnamed: R12.R1_3, R30.1
unnamed: R12.R2_1, R36.2
unnamed: R12.R2_3, R23.1
unnamed: R16.1, R37.1
unnamed: R17.1, R40.1
unnamed: R18.2, R39.1
unnamed: R19.2, R38.1
unnamed: R22.2, R36.1
unnamed: R29.2, R34.1
unnamed: C11.1, R6.2, R9.R1_1, U3.2 (1INPUT-)
unnamed: C11.2, C15.1, R9.R1_2, U3.1 (1OUT)
unnamed: C13.2, R8.2, R9.R2_1, U3.6 (2INPUT-)
unnamed: C13.1, C16.1, R9.R2_2, U3.7 (2OUT)
unnamed: C21.1, R25.2, R28.2, R30.2, U4.1 (1OUT)
unnamed: C22.1, R13.2, R21.2, R23.2, U4.7 (2OUT)
Rbuff: C16.2, R14.1, R20.1, R22.1, TP8.1
VCC: C9.1, C17.1, C18.1, C31.1, R1.2, R2.2, R3.1, R18.1, R19.1, TP13.1, U3.8 (V+), U4.8 (V+); also elsewhere on the board
Vbias: C9.2, C10.1, R3.2, R4.1, TP14.1, U3.3 (1INPUT+), U3.5 (2INPUT+), U4.3 (1INPUT+), U4.5 (2INPUT+)

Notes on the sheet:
R10 bass R11 middle R12 high
NOTE: The chassy of the 4 pot need to be connected to earth to avoid interference
2x22k=44k out impedance/line 44k value is not commercially available
Vbias ref voltage
Input buffer & master volume control
middle point => gain= 1x (with offset) full rotation => gain= 0.5x zero rotation => gain= 2x
middle point => gain= 1x full rotation => gain= 2x zero rotation => gain= 0x

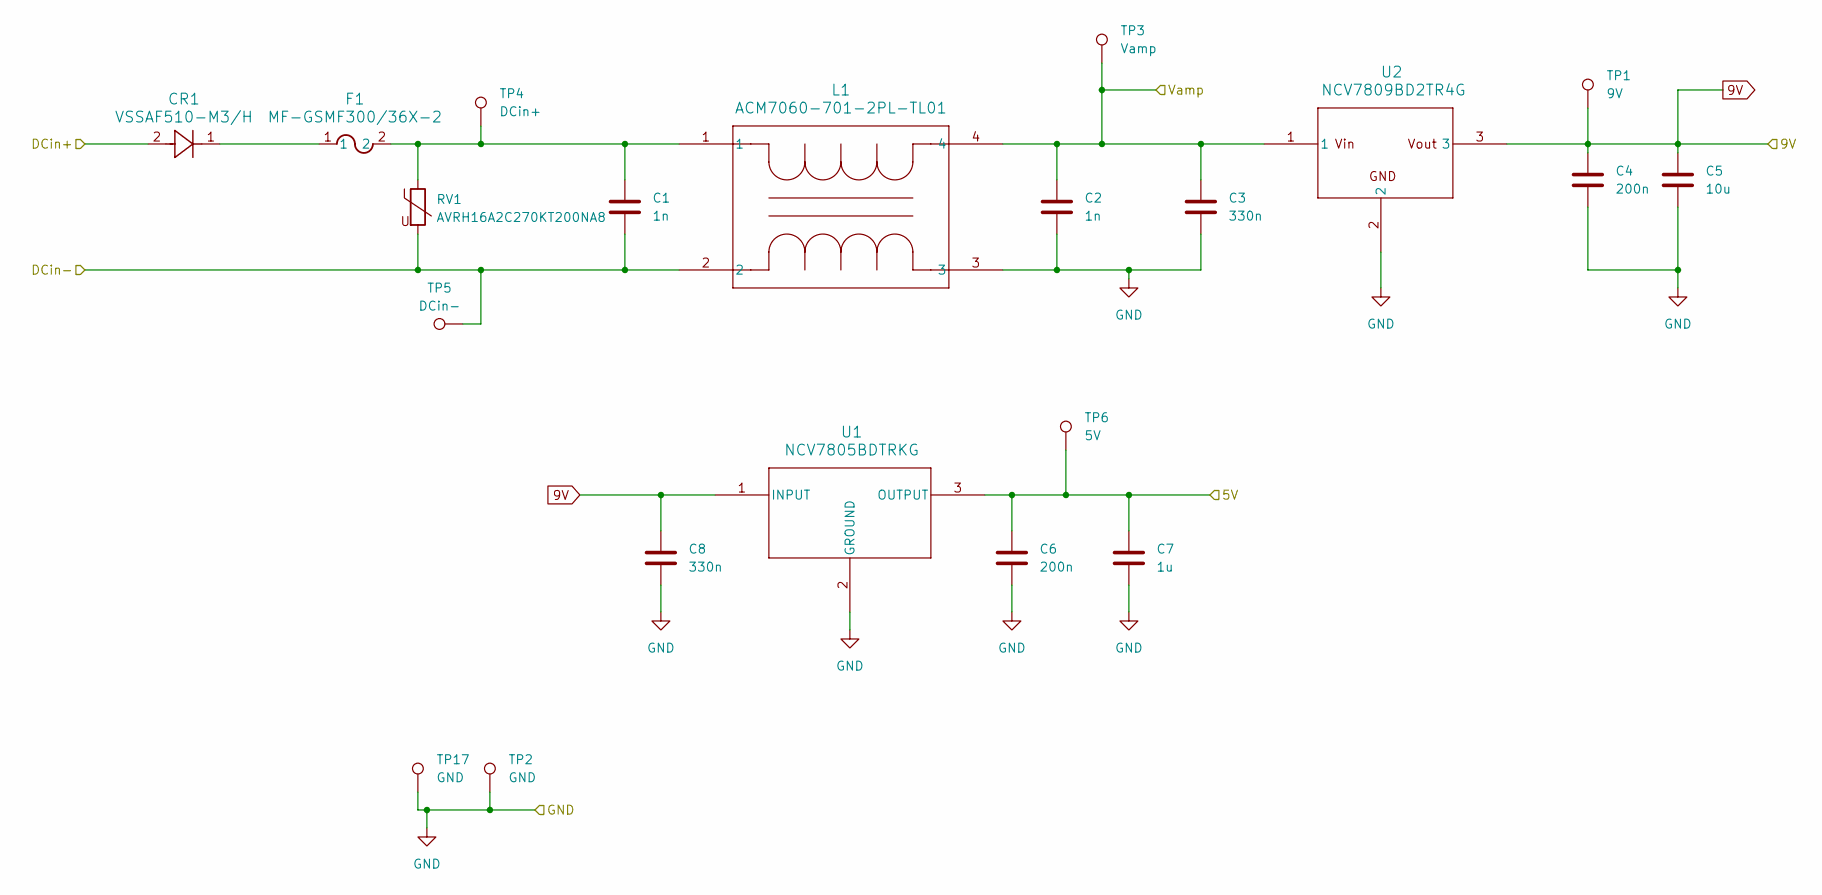
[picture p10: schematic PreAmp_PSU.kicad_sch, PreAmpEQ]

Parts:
C1, C2: 1n; C_0805_2012Metric_Pad1.18x1.45mm_HandSolder
C3, C8: 330n; C_0805_2012Metric_Pad1.18x1.45mm_HandSolder
C4, C6: 200n; C_0805_2012Metric_Pad1.18x1.45mm_HandSolder
C5: 10u; C_0805_2012Metric_Pad1.18x1.45mm_HandSolder
C7: 1u; C_0805_2012Metric_Pad1.18x1.45mm_HandSolder
CR1: VSSAF510-M3/H; CR_SLIMSMA_DO-221AC_VIS
F1: MF-GSMF300/36X-2; FUSE_MF-GSMF_BRN
L1: ACM7060-701-2PL-TL01; IND_ACM7060_TDK
RV1: AVRH16A2C270KT200NA8; R_0603_1608Metric_Pad0.98x0.95mm_HandSolder
TP1: 9V; TestPoint_Loop_D2.50mm_Drill1.85mm
TP2, TP17: GND; TestPoint_Loop_D2.50mm_Drill1.85mm
TP3: Vamp; TestPoint_Loop_D2.50mm_Drill1.85mm
TP4: DCin+; TestPoint_Loop_D2.50mm_Drill1.85mm
TP5: DCin-; TestPoint_Loop_D2.50mm_Drill1.85mm
TP6: 5V; TestPoint_Loop_D2.50mm_Drill1.85mm
U1: NCV7805BDTRKG; DPAK-3_ONS
U2: NCV7809BD2TR4G; D2PAK3_ONS

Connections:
5V: C6.1, C7.1, TP6.1, U1.3 (OUTPUT); also elsewhere on the board
9V: C4.1, C5.1, C8.1, TP1.1, U1.1 (INPUT), U2.3; also elsewhere on the board
/PreAmp_PSU/DCin+: CR1.2; also elsewhere on the board
/PreAmp_PSU/DCin-: C1.2, L1.2, RV1.2, TP5.1; also elsewhere on the board
/PreAmp_PSU/Vamp: C2.1, C3.1, L1.4, TP3.1, U2.1; also elsewhere on the board
GND: C2.2, C3.2, C4.2, C5.2, C6.2, C7.2, C8.2, L1.3, TP2.1, TP17.1, U1.2 (GROUND), U2.2, U2.4; also elsewhere on the board
unnamed: C1.1, F1.2, L1.1, RV1.1, TP4.1
unnamed: CR1.1, F1.1

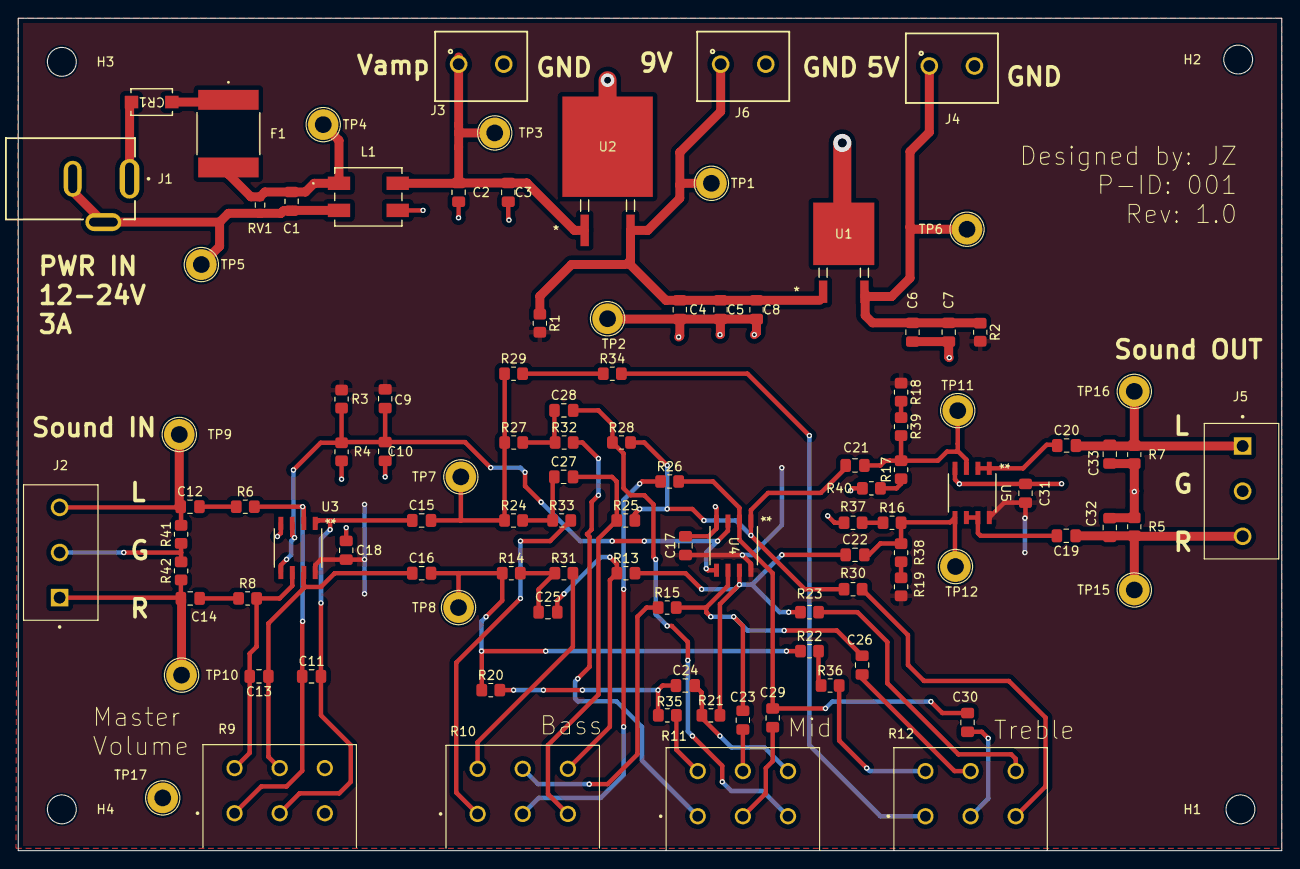
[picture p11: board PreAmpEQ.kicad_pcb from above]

Board: 2 copper layers, 140.0 x 92.2 mm, 109 parts (0 on the bottom side), 58 nets.

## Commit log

2025-03-09 Update README.md
    updated state of the main PCB mounting whole situation
2025-03-09 Added Electronic design files
    All the design files for the electronic/electrical section of the project is attached
    [PreAmpEQ-B_Cu.gbl, PreAmpEQ-B_Mask.gbs, PreAmpEQ-B_Paste.gbp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]
